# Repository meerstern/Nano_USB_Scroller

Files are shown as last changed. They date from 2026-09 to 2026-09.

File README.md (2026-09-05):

# Overview
  * This board is equipped with scroll and center button functions.  
  * It supports vertical scrolling and center button operation.  
  * Suitable for small PCs and SBCs(Single Board Computers, like Raspberry Pi).  
  * It operates using standard drivers, without the need for a dedicated driver.   
  * The vertical scrolling direction can be changed to match the USB orientation.  

# Direction Setting
  * To change the scroll direction, press and hold the center button while connecting the device to the USB port.  
  * The settings will be applied immediately.
  * If the settings are not applied, please perform the procedure again.  
  * The configuration data is automatically saved to flash memory.   
  * The orientation does not need to be set again for subsequent uses.  
  * The configuration data supports up to approximately 10,000 rewrite cycles.  
  * If you do not wish to change the orientation, connect this device to the USB port without pressing the center button.
  * To reverse the direction, perform the operation again to return it to the original state.

# Target user
  * It is ideal for users operating CAD software on a laptop.
  * It is convenient to use in combination with a [Nano USB mouse][1].  
    
# Note
  * Please take care not to short-circuit or damage components on the back of the board.    
  * Please operate gently. Operating it with excessive force may cause damage.  
  * PCB color, LED color, and other specifications are subject to change without notice.

## Appearance and examples
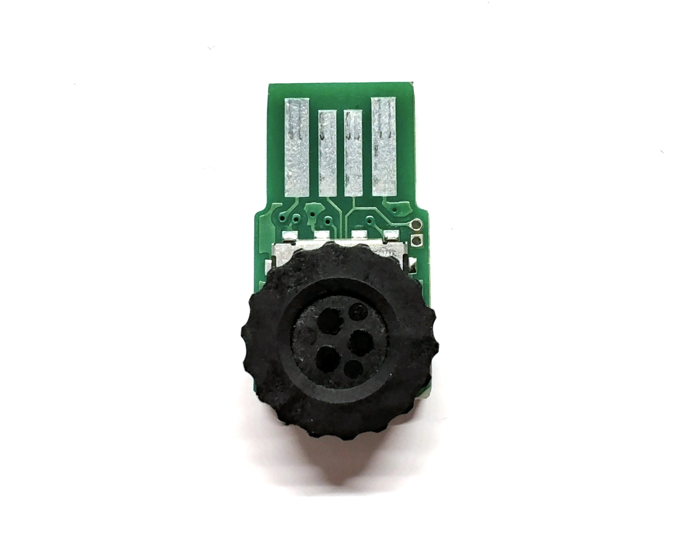
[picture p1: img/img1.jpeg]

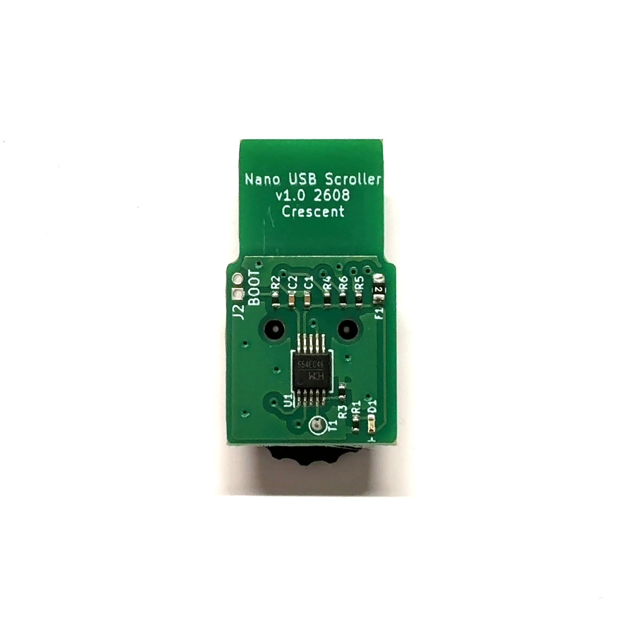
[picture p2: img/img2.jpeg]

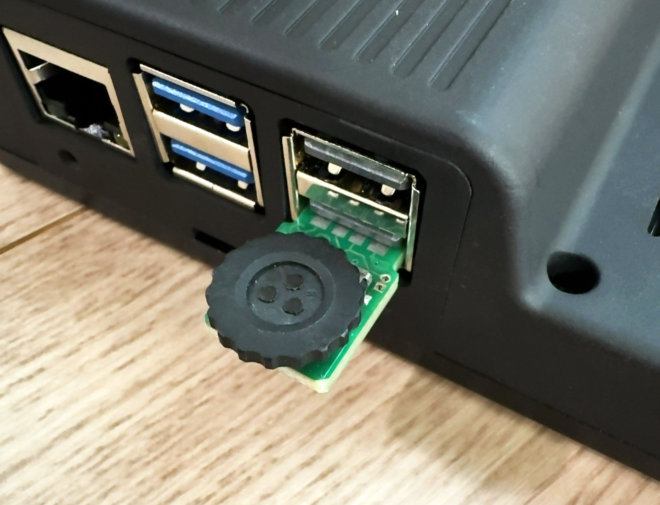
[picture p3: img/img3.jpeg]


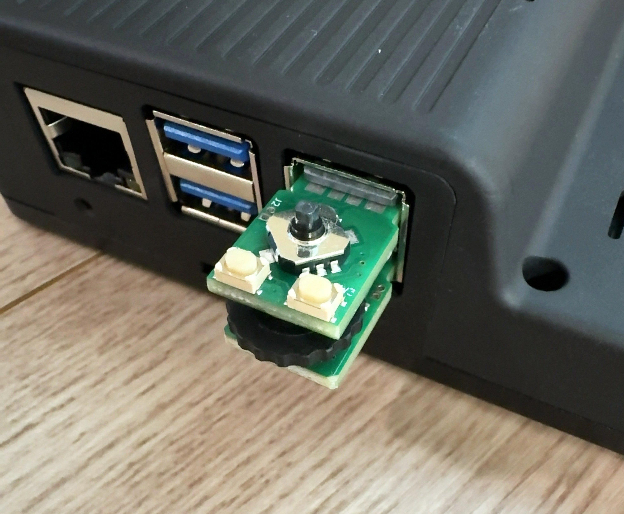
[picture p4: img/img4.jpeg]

Combination use with the USB Nano Mouse

[1]: https://github.com/meerstern/Nano_USB_Mouse/

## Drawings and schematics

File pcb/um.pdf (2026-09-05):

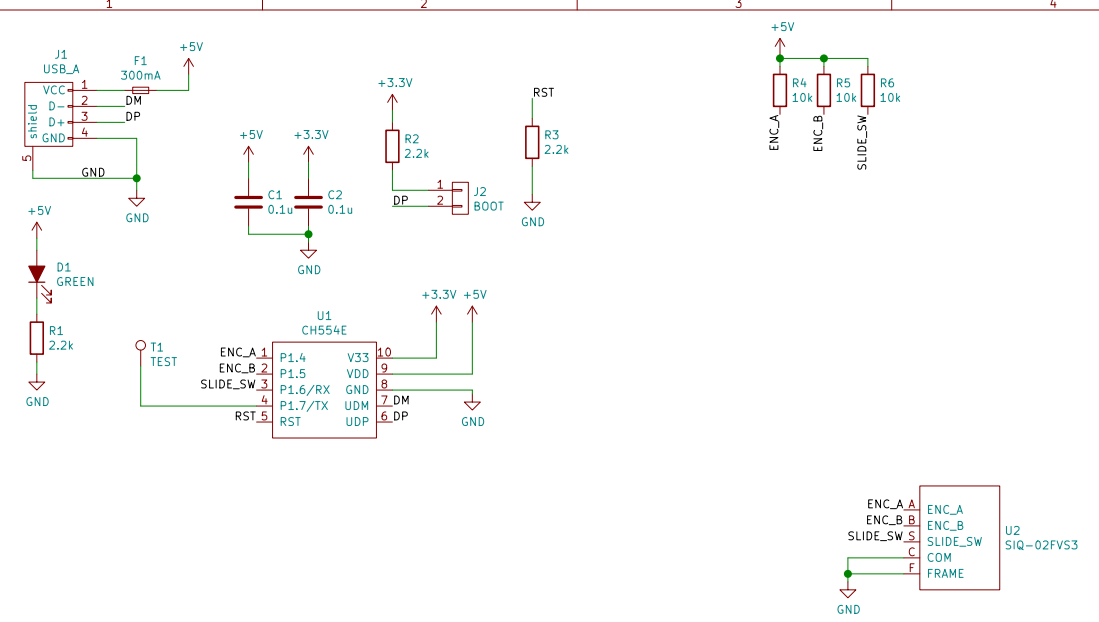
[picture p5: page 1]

Id: 1/1 Title: Nano USB Scroll File: um.sch Sheet: / Crescent

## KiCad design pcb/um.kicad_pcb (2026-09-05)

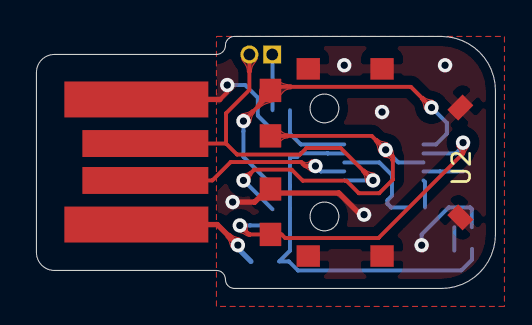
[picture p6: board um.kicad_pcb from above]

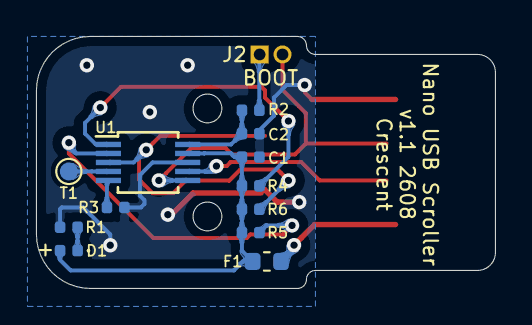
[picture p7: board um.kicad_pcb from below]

Board: 2 copper layers, 25.5 x 14.0 mm, 15 parts (12 on the bottom side), 13 nets.

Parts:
C1, C2: 0.1u; C_0402_1005Metric
D1: GREEN; LED_0402_1005Metric
F1: 300mA; Fuse_0603_1608Metric
J1: USB_A; usbpcb
J2: BOOT; PinHeader_2x01_P1.27mm_Vertical
R1, R2, R3: 2.2k; R_0402_1005Metric
R4, R5, R6: 10k; R_0402_1005Metric
T1: TEST; TestPoint_Pad_D1.0mm
U1: CH554E; MSOP-10_3x3mm_P0.5mm
U2: SIQ-02FVS3

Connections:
+3V3: C2.1, R2.1, U1.10
+5V: C1.1, D1.2, F1.2, R4.1, R5.1, R6.1, U1.9
/DM: J1.2, U1.7
/DP: J1.3, J2.2, U1.6
/ENC_A: R4.2, U1.1, U2.A
/ENC_B: R5.2, U1.2, U2.B
/RST: R3.1, U1.5
/SLIDE_SW: R6.2, U1.3, U2.S
GND: C1.2, C2.2, J1.4, R1.2, R3.2, U1.8, U2.C, U2.F
unnamed: D1.1, R1.1
unnamed: F1.1, J1.1
unnamed: J2.1, R2.2
unnamed: T1.1, U1.4

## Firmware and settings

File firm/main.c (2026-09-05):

#include <stdio.h>
#include <stdint.h>
#include <stdlib.h>
#include <stdbool.h>
#include "debug.h"

#include "ch554.h"
#include "mouse.h"
#include "flash.h"

#define ADDRESS_DIRECTION	0		//Flash Address for Direction Memory

#define ENC_A_PIN		4	//IN
#define ENC_B_PIN		5	//IN
#define CENTER_SW_PIN	6	//IN

#define delayUs	mDelayuS

enum
{
	FORWARD_DIR_MODE,
	REVERSE_DIR_MODE
};

SBIT(ENC_A, 	0x90, ENC_A_PIN);
SBIT(ENC_B, 	0x90, ENC_B_PIN);
SBIT(CENTER_SW, 0x90, CENTER_SW_PIN);

static bool centerSwOld = true;

static uint8_t encoder_state;
static short encoder_delta = 0;
static short encoder_delta_old = 0;
static uint8_t dirMode = FORWARD_DIR_MODE;


void gpio_interrupt(void) __interrupt(INT_NO_GPIO)
{
	uint8_t state;
	uint8_t transition;

    // Get P1.4/P1.5 
    state = (P1 >> 4) & 0x03;
   
    // Old -> Now
    transition = (encoder_state << 2) | state;

    switch (transition)
    {        
        case 0x01:  // 00 -> 01
        case 0x07:  // 01 -> 11
        case 0x0E:  // 11 -> 10
        case 0x08:  // 10 -> 00
            encoder_delta++;
            break;

        case 0x02:  // 00 -> 10
        case 0x0B:  // 10 -> 11
        case 0x0D:  // 11 -> 01
        case 0x04:  // 01 -> 00
            encoder_delta--;
            break;

        default:
            break;
    }

    encoder_state = state;	
}

void initGPIO(void)
{	
	//Input Pullup
	P1_MOD_OC &= ~(1 << ENC_A_PIN);
    P1_DIR_PU |= (1<<ENC_A_PIN);	
	
	P1_MOD_OC &= ~(1 << ENC_B_PIN);
    P1_DIR_PU |= (1<<ENC_B_PIN);	
	
	P1_MOD_OC &= ~(1 << CENTER_SW_PIN);
    P1_DIR_PU |= (1<<CENTER_SW_PIN);	
}


void enableInterruptGPIO()
{
	GPIO_IE &= ~bIE_IO_EDGE; 
	GPIO_IE |= bIE_P1_4_LO;
	GPIO_IE |= bIE_P1_5_LO;
	//GPIO_IE |= bIE_RXD1_LO;//P1.6
	IE_GPIO  = 1; 
	//IE_EX |= IE_GPIO;
	EA = 1;
}


void main()
{
	CfgFsys();
	mInitSTDIO();
	initGPIO();
	enableInterruptGPIO();
	
	unsigned char direction = FORWARD_DIR_MODE;
	readDataFlash(ADDRESS_DIRECTION, &direction, 1);
	if(CENTER_SW == 0)//Pushed
	{
		if(direction == REVERSE_DIR_MODE)
			direction = FORWARD_DIR_MODE;
		else
			direction = REVERSE_DIR_MODE;
		
		writeDataFlash(ADDRESS_DIRECTION, &direction, 1);	
	}
	
	mouse_init();

	while(1)
	{
		bool centerSw = CENTER_SW;
		if( encoder_delta!=encoder_delta_old && abs(encoder_delta-encoder_delta_old)<100  && abs(encoder_delta-encoder_delta_old) > 1 
			|| centerSw!=centerSwOld)
		{
			
			uint8_t button = (CENTER_SW==0)?MOUSE_MIDDLE_BUTTON:0;
			int8_t wheel = encoder_delta;
			if(direction == REVERSE_DIR_MODE)
				wheel = -1*wheel;
			hidValueHandle(button, 0, 0, wheel);			
			//printf("Val: %d\n",encoder_delta);
			encoder_delta = 0;
			encoder_delta_old = encoder_delta;
			centerSwOld = centerSw;	
			mDelaymS(5);			
		}		
	}
}

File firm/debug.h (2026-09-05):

/* Debug */
/* Provide printf subroutine and delay function */

#pragma once

#include <stdint.h>
#include "ch554.h"

#ifndef  UART0_BAUD
#define  UART0_BAUD    115200
#endif

#ifndef UART1_BAUD
#define  UART1_BAUD    115200
#endif

void	CfgFsys( );                       // CH554 clock selection and configuration

void mDelayuS (uint16_t n); // Delay in units of uS
void mDelaymS (uint16_t n); // Delay in mS

/*******************************************************************************
* Function Name  : CH554UART0Alter()
* Description    : CH554 serial port 0 pin mapping, serial port mapping to P0.2 and P0.3

*******************************************************************************/
/*
inline void CH554UART0Alter()
{
    PIN_FUNC |= bUART0_PIN_X;           //串口映射到P1.2和P1.3
}
*/

/*******************************************************************************
* Function Name  : mInitSTDIO()
* Description    : CH554 serial port 0 is initialized, T1 is used as the baud rate generator of UART0 by default, T2 can also be used
                   As a baud rate generator
*******************************************************************************/
inline void	mInitSTDIO( )
{
    /*uint32_t x;
    uint8_t x2;

    SM0 = 0;
    SM1 = 1;
    SM2 = 0;                                                                   //Serial port 0 usage mode 1
                                                                               //Use Timer1 as a baud rate generator
    RCLK = 0;                                                                  //UART0 receive clock
    TCLK = 0;                                                                  //UART0 transmit clock
    PCON |= SMOD;
    x = 10 * FREQ_SYS / UART0_BAUD / 16;                                       //If you change the main frequency, be careful not to overflow the value of x
    x2 = x % 10;
    x /= 10;
    if ( x2 >= 5 ) x ++;                                                       //rounding

    TMOD = TMOD & ~ bT1_GATE & ~ bT1_CT & ~ MASK_T1_MOD | bT1_M1;              //0X20, Timer1 as 8-bit auto-reload timer
    T2MOD = T2MOD | bTMR_CLK | bT1_CLK;                                        //Timer1 clock selection
    TH1 = 0-x;                                                                 //12MHz crystal oscillator, buad / 12 is the actual need to set the baud rate
    TR1 = 1;                                                                   //Start timer 1
    TI = 1;
    REN = 1;                                                                   //Serial 0 receive enable
	*/
	unsigned long baud;
	//uint8_t alt;
	baud = 9600;//115200;
	//alt=0;
	unsigned long x;
	
	/*
	if(alt){
		P1_MOD_OC &= (~bTXD1_);
		P1_DIR_PU |= bTXD1_ | bRXD1_;
		PIN_FUNC |= bUART1_PIN_X;
	}
	else{
		P3_MOD_OC &= (~bTXD1);
		P3_DIR_PU |= bTXD1 | bRXD1;
		PIN_FUNC &= (~bUART1_PIN_X);
	}*/
	
	P3_MOD_OC &= (~bTXD1);
	P3_DIR_PU |= bTXD1 | bRXD1;
	PIN_FUNC &= (~bUART1_PIN_X);

 	U1SM0 = 0;
	//U1REN = 1;
	U1SMOD = 1;
	//Register SBAUD1 determines the baud rate.
	//SBAUD1 value should be 256-Fsys/16/(baud rate)
	//this fomula is equivalent to round(FREQ_SYS/16/baud)
    x = (((unsigned long)FREQ_SYS / 8) / baud + 1) / 2;

    SBAUD1 = (256 - x) & 255;
	U1TI = 0;
	
}

/*******************************************************************************
* Function Name  : CH554UART0RcvByte()
* Description    : CH554UART0 receives a byte
* Return         : SBUF
*******************************************************************************/
/*
inline uint8_t  CH554UART0RcvByte( )
{
    while(RI == 0);                     // wait for uart rx interrupt flag
    RI = 0;
    return SBUF;
}
*/
/*******************************************************************************
* Function Name  : CH554UART0SendByte(uint8_t SendDat)
* Description    : CH554UART0 sends a byte
* Input          : uint8_t SendDat; the data to be sent
*******************************************************************************/
/*
inline void CH554UART0SendByte(uint8_t SendDat)
{
	SBUF = SendDat;
	while(TI ==0);                  // wait for transmit to finish (TI == 1)
	TI = 0;
}
*/
/*******************************************************************************
* Function Name  : CH554UART1Alter()
* Description    : Set the alternate pin mappings for UART1 (TX on P3.2, RX on P3.4)
*******************************************************************************/
/*
inline void CH554UART1Alter()
{
    PIN_FUNC |= bUART1_PIN_X;
}
*/
/*******************************************************************************
* Function Name  : UART1Setup()
* Description    : CH554串口1初始化
*******************************************************************************/
/*
inline void	UART1Setup()
{
    U1SM0 = 0;                          //UART1选择8位数据位
    U1SMOD = 1;                         //快速模式
    U1REN = 1;                          //使能接收
    // should correct for rounding in SBAUD1 calculation 
    SBAUD1 = 256 - FREQ_SYS/16/UART1_BAUD;
}
*/
/*******************************************************************************
* Function Name  : CH554UART1RcvByte()
* Description    : CH554UART1接收一个字节
* Return         : SBUF
*******************************************************************************/
/*
inline uint8_t  CH554UART1RcvByte( )
{
    while(U1RI == 0);                   //查询接收，中断方式可不用
    U1RI = 0;
    return SBUF1;
}
*/
/*******************************************************************************
* Function Name  : CH554UART1SendByte(uint8_t SendDat)
* Description    : CH554UART1发送一个字节
* Input          : uint8_t SendDat；要发送的数据
*******************************************************************************/
/*
inline void CH554UART1SendByte(uint8_t SendDat)
{
        SBUF1 = SendDat;                //查询发送，中断方式可不用下面2条语句,但发送前需TI=0
        while(U1TI ==0);
        U1TI = 0;
}
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
